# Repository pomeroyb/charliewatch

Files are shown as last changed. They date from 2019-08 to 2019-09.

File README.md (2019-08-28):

ChuckWatch
-----
This is a version of [OSResearch's excellent CharlieWatch](https://github.com/osresearch/charliewatch) with a bit more functionality. It adds an [LIS3DH](https://www.st.com/content/ccc/resource/technical/document/datasheet/3c/ae/50/85/d6/b1/46/fe/CD00274221.pdf/files/CD00274221.pdf/jcr:content/translations/en.CD002742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) accelerometer. This will eventually allow the watch to respond to taps, opening up possibilities for interaction and setting of time.

Original README
------

Watch rendering

"Analog" watch with 60+12 Charlieplexed LEDs. Based on Travis Goodspeed's
GoodWatch21 schematic, using the CC430F5137IRGZR CPU, which doesn't
have the LCD controller of the CC430F6xxx in the GoodWatch. There are
also pads for a six pin EZfet cable with pogopins for programming or
serial communication.

v0.2 board, populated
v0.2 works, although it has no radio parts.  It is exactly 1 square inch
of PCB and should fit in a 38mm or 36mm case.

v0.1 board
v0.1 works, although the radio parts have not been tested.  It is a slightly
larger board and fits in a 40mm case.

[Charliewtch schematic](datasheets/charliewatch.pdf)

Programming cable
-----

From the top of the v0.1 board:
* RST / TDIO
* RXD on programmer
* TXD on programmer
* VCC
* TST / TCK
* GND

v0.2:
* greem
* white
* blue
* purple
* gray
* black

There is also a four-wire setup that might simplify the wiring.
Travis documents it and the power consumption here:
https://github.com/travisgoodspeed/goodwatch/wiki/EnergyTrace

Bricked Launchpad
-----

If you brick your launchpad by running Energia under Linux, it will no
longer program the Charliewatch.  The other weirdness is that `tilib`
can detect the device, but can't write to it unless run as root.

Energy Trace
----
* `libmsp430.so`: https://dlbeer.co.nz/articles/slac460y/index.html
* https://github.com/carrotIndustries/energytrace-util
* Have to update path to `MSP430.h` from the `slac/DLL430_v3/include` directory

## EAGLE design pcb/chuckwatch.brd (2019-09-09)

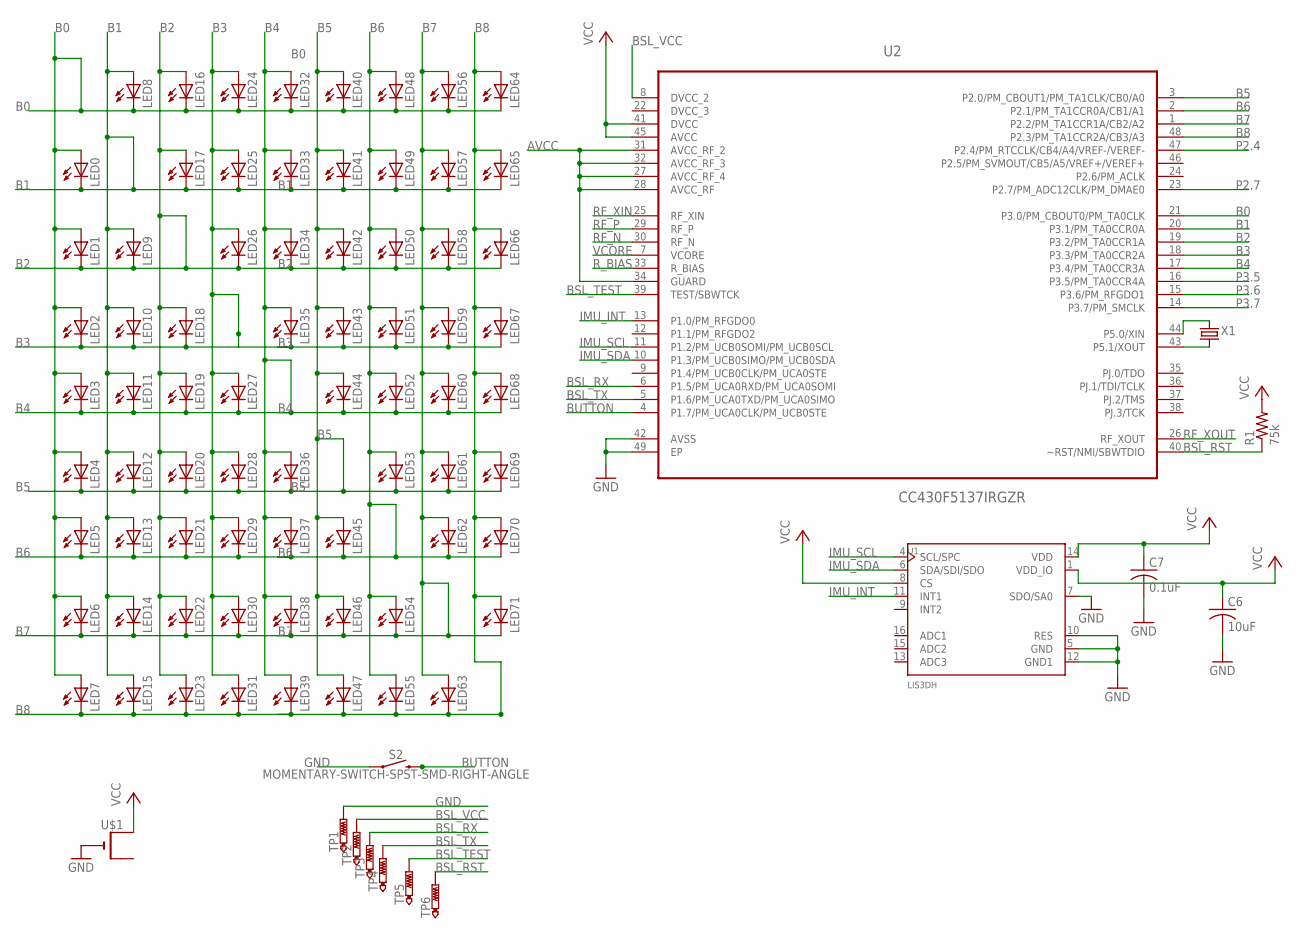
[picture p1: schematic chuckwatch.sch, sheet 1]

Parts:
C6: 10uF; C0603
C7: 0.1uF; C0603
LED0, LED1, LED2, LED3, LED4, LED5, LED6, LED7, LED8, LED9, LED10, LED11, LED12, LED13, LED14, LED15, LED16, LED17, LED18, LED19, LED20, LED21, LED22, LED23, LED24, LED25, LED26, LED27, LED28, LED29, LED30, LED31, LED32, LED33, LED34, LED35, LED36, LED37, LED38, LED39, LED40, LED41, LED42, LED43, LED44, LED45, LED46, LED47, LED48, LED49, LED50, LED51, LED52, LED53, LED54, LED55, LED56, LED57, LED58, LED59, LED60, LED61, LED62, LED63, LED64, LED65, LED66, LED67, LED68, LED69, LED70, LED71: LEDCHIPLED_0603; CHIPLED_0603
R1: 75k; R0402
S2: MOMENTARY-SWITCH-SPST-SMD-RIGHT-ANGLE; TACTILE_SWITCH_SMD_RIGHT_ANGLE
TP1: PTR1TP10SQ; TP10SQ
TP2, TP3, TP4, TP5, TP6: PTR1TP10R; TP10R
U1: LIS3DH; PQFN50P300X300X100-16N
U2: CC430F5137IRGZR; QFN50P700X700X100-49N
U$1: CR2032SMT; CR2032-SMD
X1: CRYSTALS-NOGND-IQXC-25; 2.0X1.2-2PAD

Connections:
AVCC: U2.27 (AVCC_RF_4), U2.28 (AVCC_RF), U2.31 (AVCC_RF_2), U2.32 (AVCC_RF_3), U2.34 (GUARD)
B0: LED0.A, LED1.A, LED2.A, LED3.A, LED4.A, LED5.A, LED6.A, LED7.A, LED8.C, LED16.C, LED24.C, LED32.C, LED40.C, LED48.C, LED56.C, LED64.C, U2.21 (P3.0/PM_CBOUT0/PM_TA0CLK)
B1: LED0.C, LED8.A, LED9.A, LED10.A, LED11.A, LED12.A, LED13.A, LED14.A, LED15.A, LED17.C, LED25.C, LED33.C, LED41.C, LED49.C, LED57.C, LED65.C, U2.20 (P3.1/PM_TA0CCR0A)
B2: LED1.C, LED9.C, LED16.A, LED17.A, LED18.A, LED19.A, LED20.A, LED21.A, LED22.A, LED23.A, LED26.C, LED34.C, LED42.C, LED50.C, LED58.C, LED66.C, U2.19 (P3.2/PM_TA0CCR1A)
B3: LED2.C, LED10.C, LED18.C, LED24.A, LED25.A, LED26.A, LED27.A, LED28.A, LED29.A, LED30.A, LED31.A, LED35.C, LED43.C, LED51.C, LED59.C, LED67.C, U2.18 (P3.3/PM_TA0CCR2A)
B4: LED3.C, LED11.C, LED19.C, LED27.C, LED32.A, LED33.A, LED34.A, LED35.A, LED36.A, LED37.A, LED38.A, LED39.A, LED44.C, LED52.C, LED60.C, LED68.C, U2.17 (P3.4/PM_TA0CCR3A)
B5: LED4.C, LED12.C, LED20.C, LED28.C, LED36.C, LED40.A, LED41.A, LED42.A, LED43.A, LED44.A, LED45.A, LED46.A, LED47.A, LED53.C, LED61.C, LED69.C, U2.3 (P2.0/PM_CBOUT1/PM_TA1CLK/CB0/A0)
B6: LED5.C, LED13.C, LED21.C, LED29.C, LED37.C, LED45.C, LED48.A, LED49.A, LED50.A, LED51.A, LED52.A, LED53.A, LED54.A, LED55.A, LED62.C, LED70.C, U2.2 (P2.1/PM_TA1CCR0A/CB1/A1)
B7: LED6.C, LED14.C, LED22.C, LED30.C, LED38.C, LED46.C, LED54.C, LED56.A, LED57.A, LED58.A, LED59.A, LED60.A, LED61.A, LED62.A, LED63.A, LED71.C, U2.1 (P2.2/PM_TA1CCR1A/CB2/A2)
B8: LED7.C, LED15.C, LED23.C, LED31.C, LED39.C, LED47.C, LED55.C, LED63.C, LED64.A, LED65.A, LED66.A, LED67.A, LED68.A, LED69.A, LED70.A, LED71.A, U2.48 (P2.3/PM_TA1CCR2A/CB3/A3)
BSL_RST: R1.1, TP6.TP, U2.40 (~RST/NMI/SBWTDIO)
BSL_RX: TP3.TP, U2.6 (P1.5/PM_UCA0RXD/PM_UCA0SOMI)
BSL_TEST: TP5.TP, U2.39 (TEST/SBWTCK)
BSL_TX: TP4.TP, U2.5 (P1.6/PM_UCA0TXD/PM_UCA0SIMO)
BSL_VCC: TP2.TP, U2.8 (DVCC_2)
BUTTON: S2.2, U2.4 (P1.7/PM_UCA0CLK/PM_UCB0STE)
DVCC_3: U2.22 (DVCC_3)
GND: C6.2, C7.2, S2.1, TP1.TP, U1.5 (GND), U1.7 (SDO/SA0), U1.10 (RES), U1.12 (GND1), U2.42 (AVSS), U2.49 (EP), U$1.-
IMU_INT: U1.11 (INT1), U2.13 (P1.0/PM_RFGDO0)
IMU_SCL: U1.4 (SCL/SPC), U2.11 (P1.2/PM_UCB0SOMI/PM_UCB0SCL)
IMU_SDA: U1.6 (SDA/SDI/SDO), U2.10 (P1.3/PM_UCB0SIMO/PM_UCB0SDA)
P2.4: U2.47 (P2.4/PM_RTCCLK/CB4/A4/VREF-/VEREF-)
P2.7: U2.23 (P2.7/PM_ADC12CLK/PM_DMAE0)
P3.5: U2.16 (P3.5/PM_TA0CCR4A)
P3.6: U2.15 (P3.6/PM_RFGDO1)
P3.7: U2.14 (P3.7/PM_SMCLK)
RF_N: U2.30 (RF_N)
RF_P: U2.29 (RF_P)
RF_XIN: U2.25 (RF_XIN)
RF_XOUT: U2.26 (RF_XOUT)
R_BIAS: U2.33 (R_BIAS)
VCC: C6.1, C7.1, R1.2, U1.1 (VDD_IO), U1.8 (CS), U1.14 (VDD), U2.41 (DVCC), U2.45 (AVCC), U$1.+$1 (+)
VCORE: U2.7 (VCORE)
XIN: U2.44 (P5.0/XIN), X1.2
XOUT: U2.43 (P5.1/XOUT), X1.1

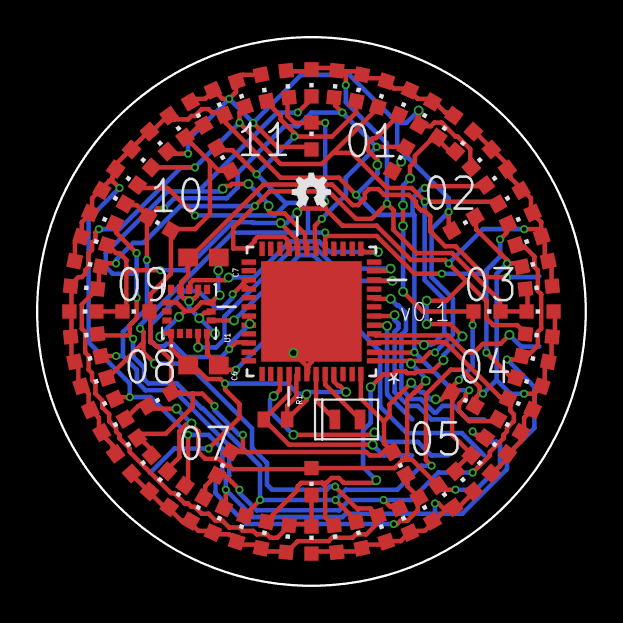
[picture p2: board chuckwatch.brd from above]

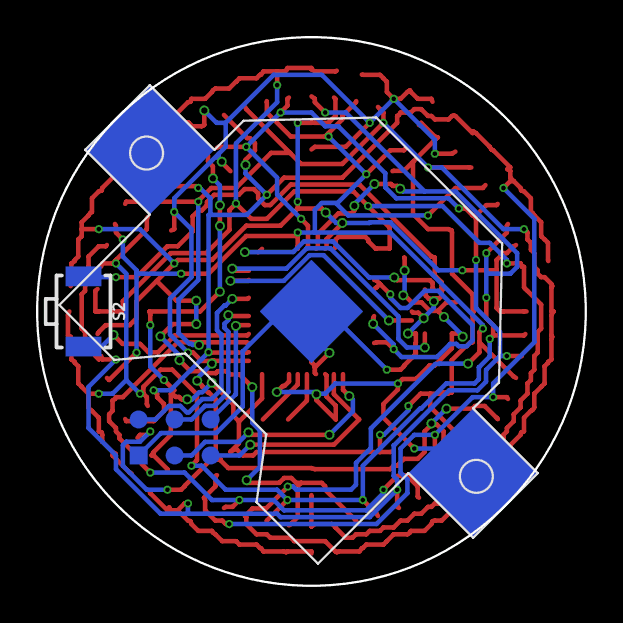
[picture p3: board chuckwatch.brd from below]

Board: 2 copper layers, 30.5 x 30.5 mm, 86 parts (8 on the bottom side), 23 nets.

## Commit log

2019-08-24 Add LIS3DH Accelerometer
    LIS3DH is an i2c accelerometer. Hope to use this to control the watch
    with tap based gestures
    [charliewatch-norf.brd, charliewatch-norf.sch, charliewatch.brd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]
2019-08-24 Consolidate watch versions
    Removed everything older versions and version with RF (a feature not to
    be used in the foreseeable future)
    [charliewatch-0402.brd, charliewatch-0402.sch, charliewatch-bicolor.brd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]
2019-08-24 Cleaned up .brd File
    The Origin of the watch is (20, 20). Can now reference from that point
    when designing
    [charliewatch-norf.brd, charliewatch-norf.sch]
2019-08-24 components place and laid out
    [charliewatch-norf.brd]
2019-08-28 Place programming pins
    Also updated version to 0.3!
    [charliewatch-norf.brd]
2019-09-09 Finish Routing
    [charliewatch-norf.brd]
2019-09-09 Chuckwatch version 0.1
    [chuckwatch.brd, chuckwatch.sch]

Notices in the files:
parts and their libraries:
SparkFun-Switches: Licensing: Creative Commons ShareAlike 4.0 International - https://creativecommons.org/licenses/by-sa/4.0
